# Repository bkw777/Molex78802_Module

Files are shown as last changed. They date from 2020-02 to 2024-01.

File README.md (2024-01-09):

# Molex78802 Module
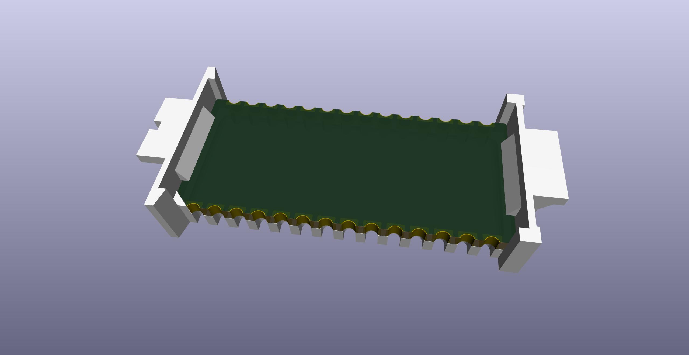
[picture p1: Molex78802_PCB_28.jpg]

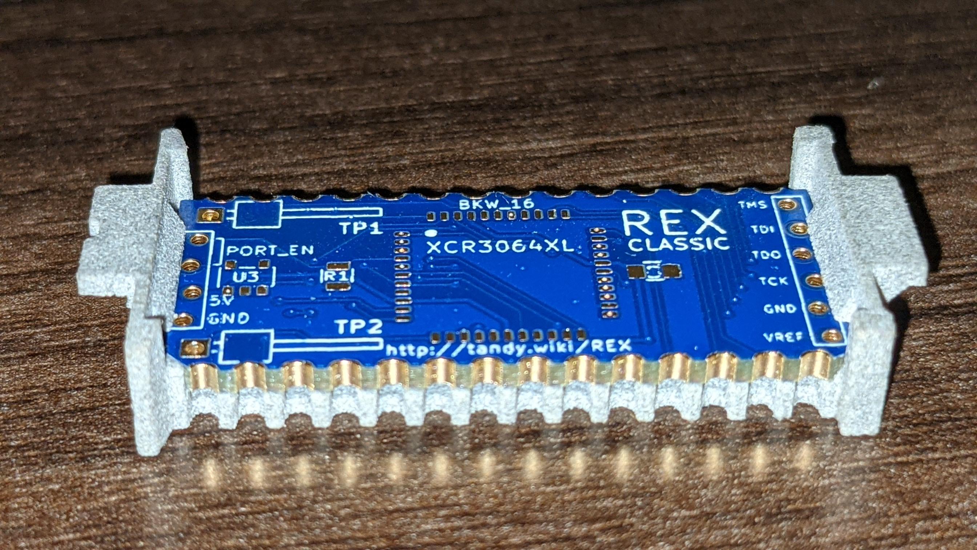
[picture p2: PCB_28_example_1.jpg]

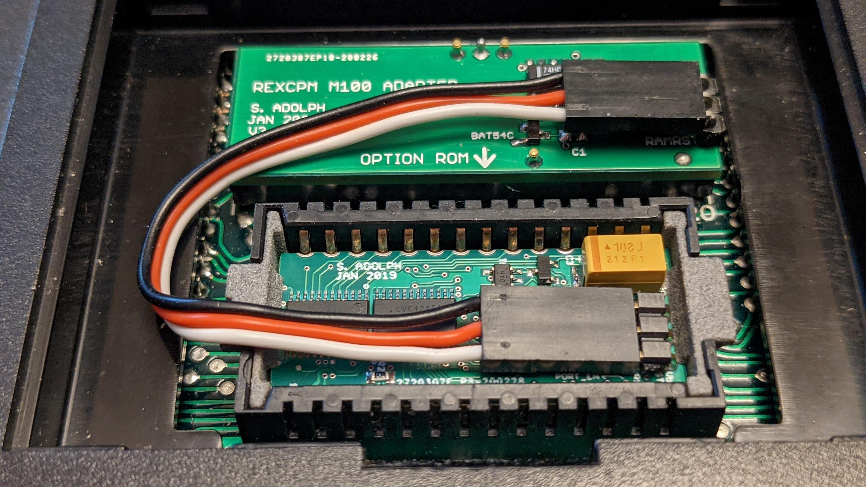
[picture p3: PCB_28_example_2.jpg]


This is a 3d-printable carrier similar to Molex 78802, to fit into a Molex 78805 socket, and a PCB template to use in place of a DIP chip.

The OpenSCAD file generates 2 types of carrier, one type that holds a DIP chip like a normal Molex 78802, and a different form that holds a PCB instead of a DIP.

The KiCAD files are for the matching PCB with the special board outline and castellated edge contacts to fit the PCB carrier. The pcbs are empty starter templates. Copy the entire PCB directory to a new project and rename the kicad_pcb file to a new name to start a new pcb.

Each of those are also available in 24, 28, and 32-pin sizes, as the original Molex [78802](references/050395288_sd_corrected.pdf) & [78805](references/015299282_sd_corrected.pdf) were.  
Though almost everything uses the 28-pin.

Uses:
* TRS-80/TANDY Model 100, 102, 200, 600
* Kyotronic KC-85
* Epson PX-4, PX-8
* Intermec 9440, Telexon 710, and various other similar hand-held teriminals
* RB5X robot (24-pin!)

http://tandy.wiki/Molex78802_Module  
https://github.com/bkw777/M4ROM  
http://tandy.wiki/Teeprom  
http://tandy.wiki/REX  

You can get 3d printed parts from Shapeways: (all versions) https://www.shapeways.com/shops/bkw  
Or use the STL files with any service.  Hint: Order pcbs like REX or M4ROM from Elecrow and order the carriers (Molex_78802_PCB_28.stl) in Nylon from them too all on the same order.
<!-- Sculpteo has a $50 minimum order, if you order less than $50 worth of parts before tax & shipping, then they charge you the difference. So you have to order 8 or 9 carriers minimum. -->
<!-- Or Sculpteo: [PCB24](https://www.sculpteo.com/en/print/molex78802_pcb_24-4/xMikpkmg), [PCB28](https://www.sculpteo.com/en/print/molex78802_pcb_28-13/Bw4x3yG6), [PCB32](https://www.sculpteo.com/en/print/molex78802_pcb_32-3/zmUBXFK4), [DIP24](https://www.sculpteo.com/en/print/molex78802_dip_24/P2V6xXt8), [DIP28](https://www.sculpteo.com/en/print/molex78802_dip_28-7/LX6JbLYc), [DIP32](https://www.sculpteo.com/en/print/molex78802_dip_32/sJC8nkke). -->

Brian K. White - b.kenyon.w@gmail.com

## DIP 24  
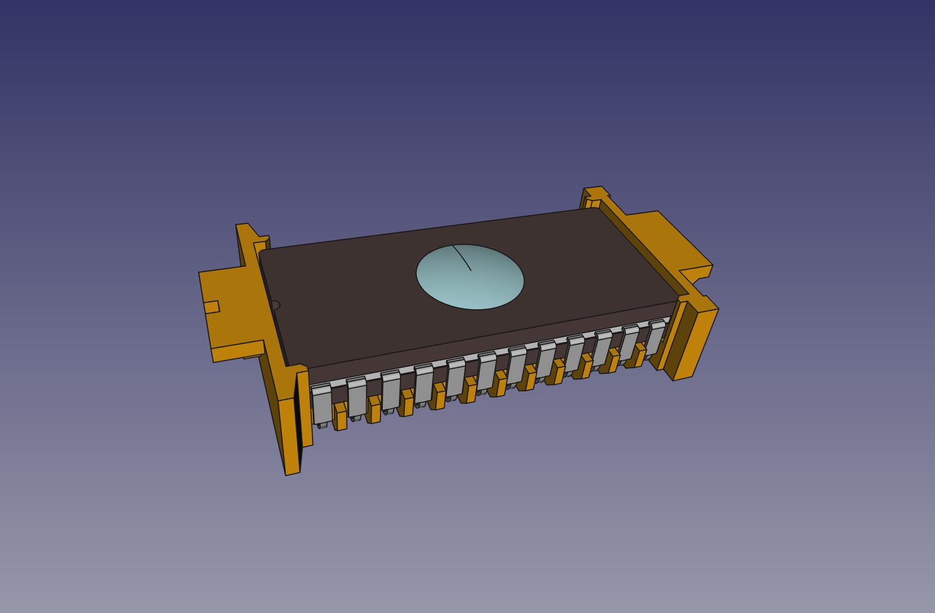
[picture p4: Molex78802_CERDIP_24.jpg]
  
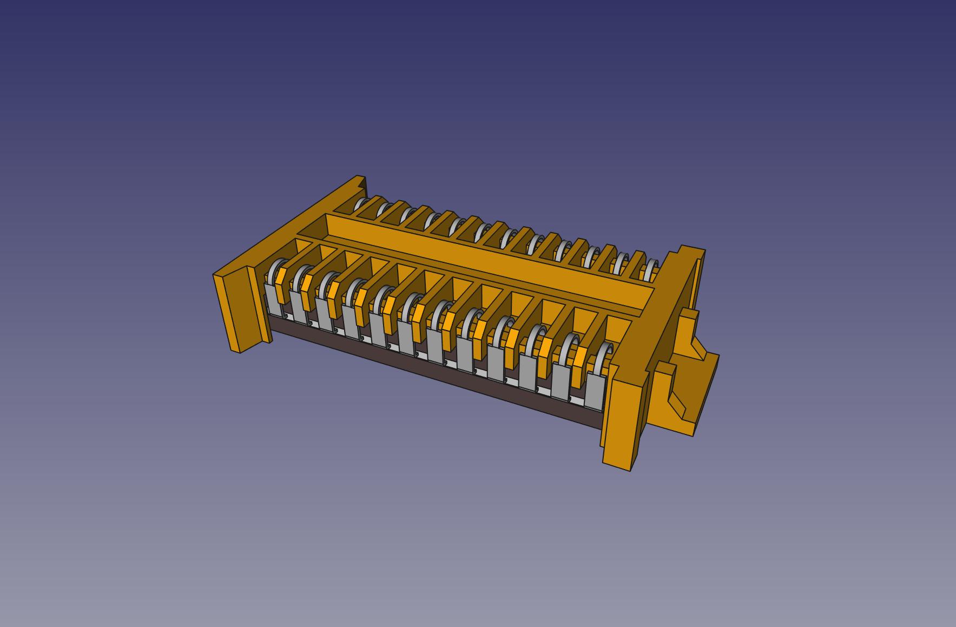
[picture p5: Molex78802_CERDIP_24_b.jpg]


## DIP 28  
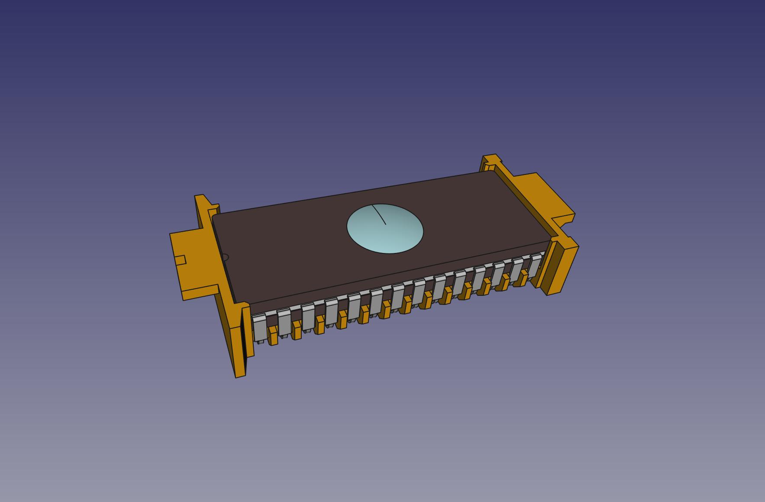
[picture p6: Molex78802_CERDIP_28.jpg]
  
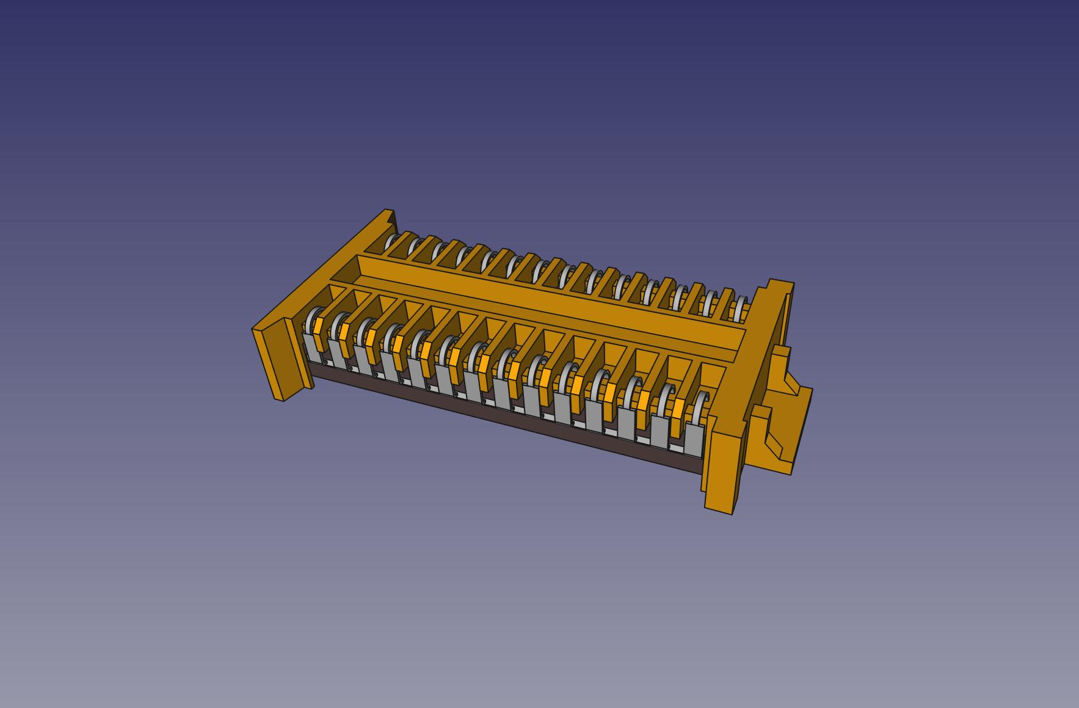
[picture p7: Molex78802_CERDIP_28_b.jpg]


## DIP 32  
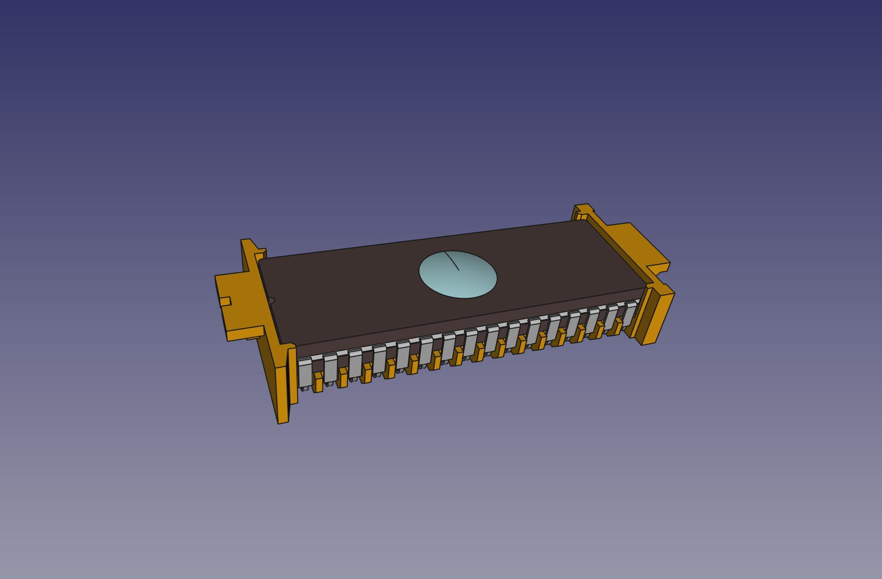
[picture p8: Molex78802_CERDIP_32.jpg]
  
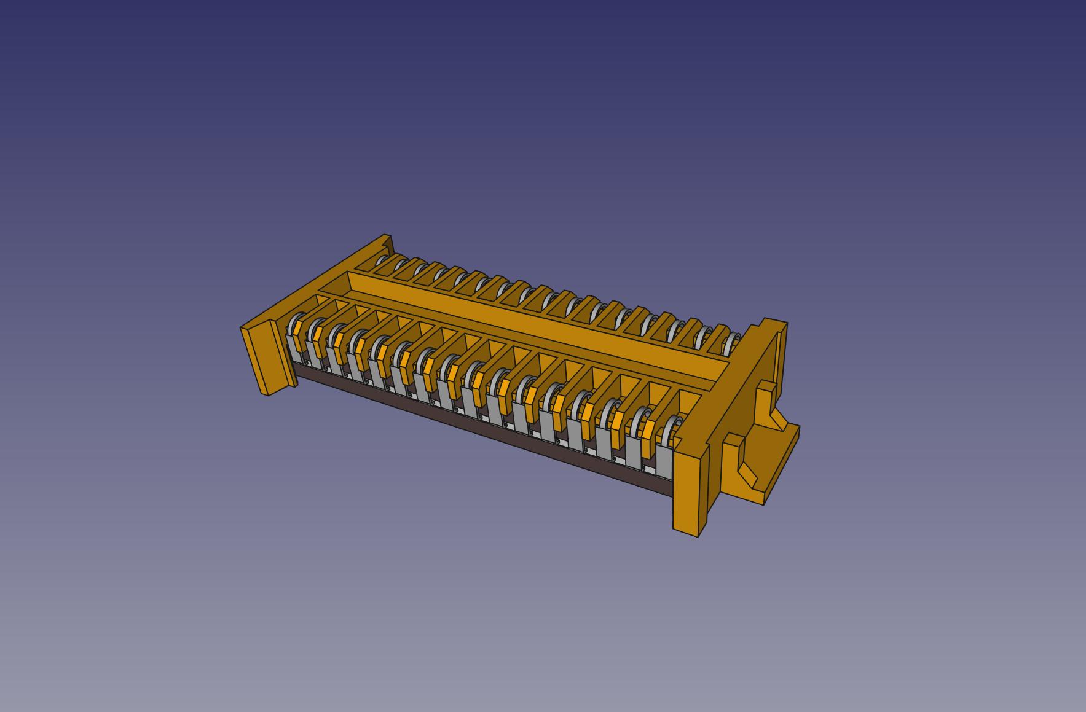
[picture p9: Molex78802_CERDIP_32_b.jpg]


## PCB 24  
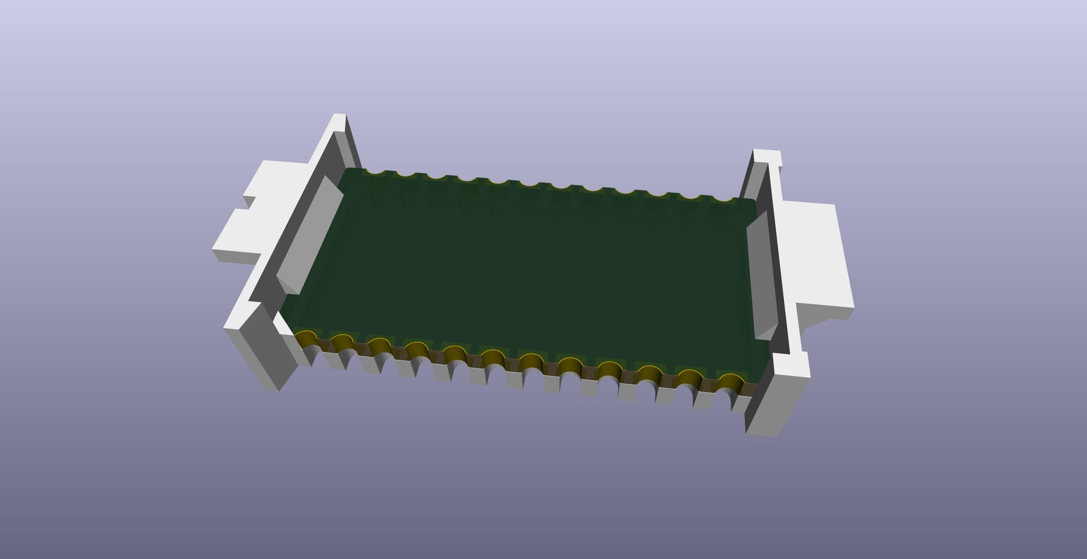
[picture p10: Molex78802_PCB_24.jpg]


## PCB 28  


## PCB 32  


***May 19 2021 - The PCB outline changed slightly after [v003](https://github.com/bkw777/Molex78802_Module/tree/v003). The PCB is a little wider now. Old boards will be a little loose side-to-side in new carriers, and probably the polarity chamfer won't prevent inserting an old board backwards in a new carrier. New boards won't fit into old carriers, although the difference is small enough that you could just sand the corners down a little and they should work fine. If you have either old carriers or old boards that you want to get the exact matching counterparts for, then go to [Release v003](https://github.com/bkw777/Molex78802_Module/releases/tag/v003).***

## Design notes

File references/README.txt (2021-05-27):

* 015299282_sd_corrected.pdf
  The data sheet for the socket has an error for the width of the interior cavity.
  It correctly says 0.665 for the width in inches, but incorrectly says 19.90 for the same dimension in mm.
  0.665 inches = 16.891 mm
  The corrected pdf changes the text "(19.90)" to "(16.89)"

* 050395288_sd_corrected.pdf
  The data sheet for the carrier has a drawing error where DIM.D and DIM.F both line up with the same feature,
  the outside edge of the left end, and no dimension lines up with the recessed edge on the left side.
  The numbers in the chart show that DIM.D is the outside edge, and DIM.F is the recessed edge.
  The corrected pdf moves the left drawing line for DIM.F slightly to the right to line up with the recessed edge on the left side.

* DIP-##_crimped.step
  Created manually using FreeCAD, starting from a DIP-28 .step from KiCAD's library.
  Used to check fitment virtually and to generate renders.

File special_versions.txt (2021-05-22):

Aside from the "DIP" and "PCB" versions, there is also a hidden "maxpcb" version.

To generate a maxpcb version, run:  
    cd Carrier && make variants=maxpcb

The maxpcb version is difficult to use, incompatible with normal REX/Teeprom/Meeprom boards, and probably never needed, so it's hidden for simplicity. But it exists to provide an option if ever really needed, that gives the absolute most possible usable pcb real-estate.

The normal PCB version has:
* A ledge running aoround the perimeter for the pcb to rest on, which consumes a 0.7mm border on all 4 sides on the bottom.
* 2 snap wedges on top that hold the pcb down, which consumes 2 1x10mm chunks on the top.
* A polarity chamfer in one corner which consumes 1.7mm of that corner on top and bottom

The maxpcb replaces all those mechanisms for holding the pcb in place with holes in the end walls, and you design the pcb board outline to have prongs that stick into those holes. This holds the pcb in place in all directions, and polarity is asserted by the fact that one hole is larger. This allows to dispense with the perimiter ledge, the snap wedges, and the chamfer. This allows not only traces but even components to exist right to the edge of the pcb on all 4 sides and on both top & bottom.

There is no kicad template for a maxpcb board at this time.

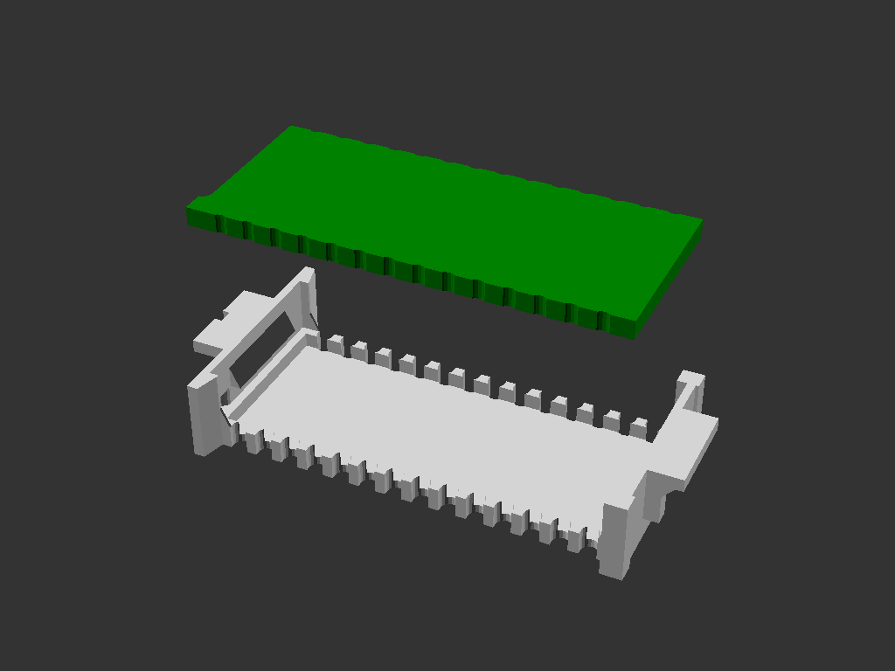
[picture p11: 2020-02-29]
pcb2molex8878_bump.png

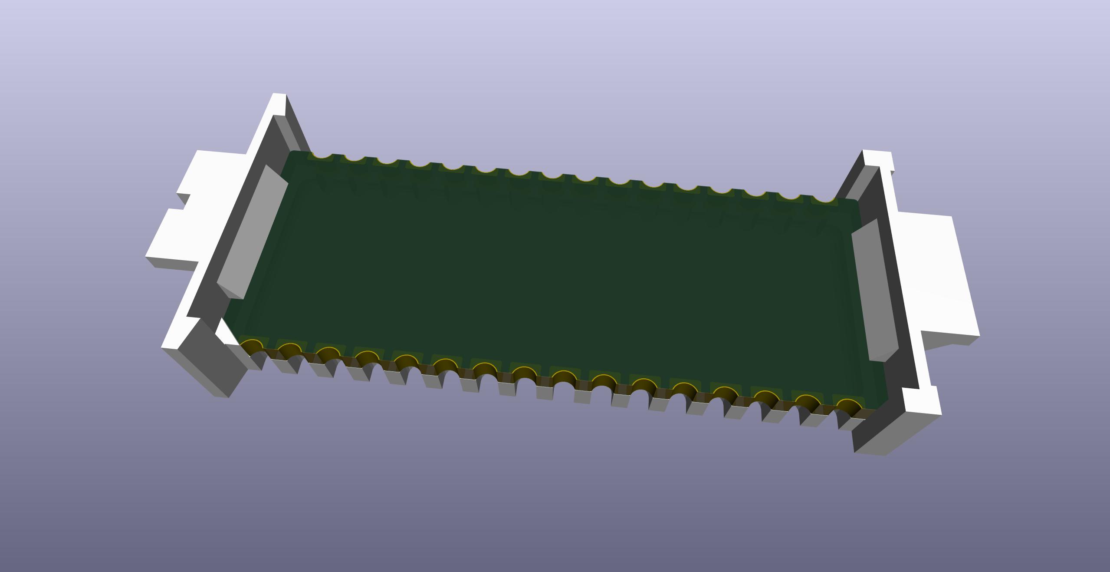
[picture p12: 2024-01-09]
Molex78802_PCB_32.jpg

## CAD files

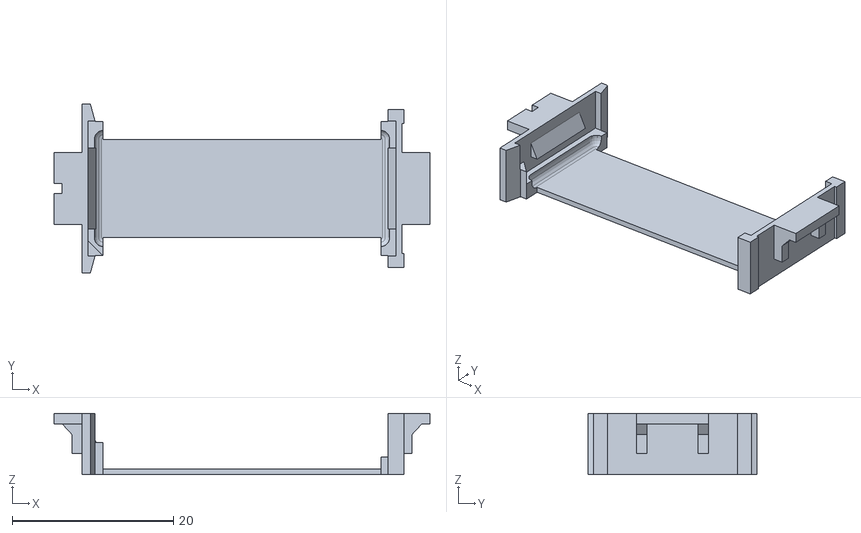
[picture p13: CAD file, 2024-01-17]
Carrier/Molex78802_PCB_28_no_fingers.stl
46.6 x 21.0 x 7.60

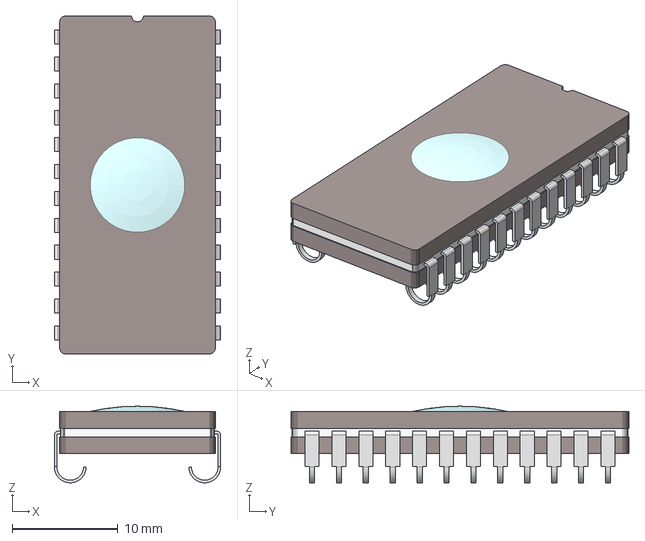
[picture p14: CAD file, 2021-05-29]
references/CERDIP_24_crimped.step
15.7 x 31.9 x 7.24 mm

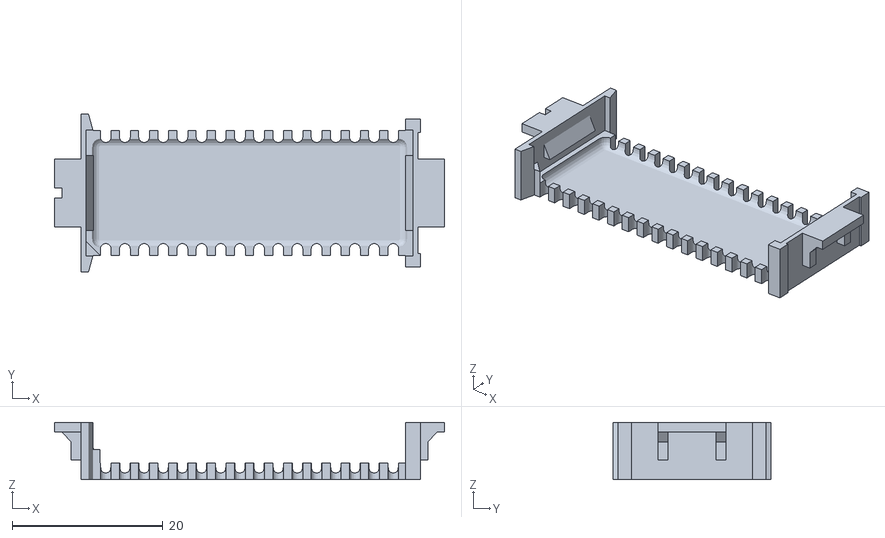
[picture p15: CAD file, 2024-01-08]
Carrier/Molex78802_PCB_32.stl
51.7 x 21.0 x 7.60

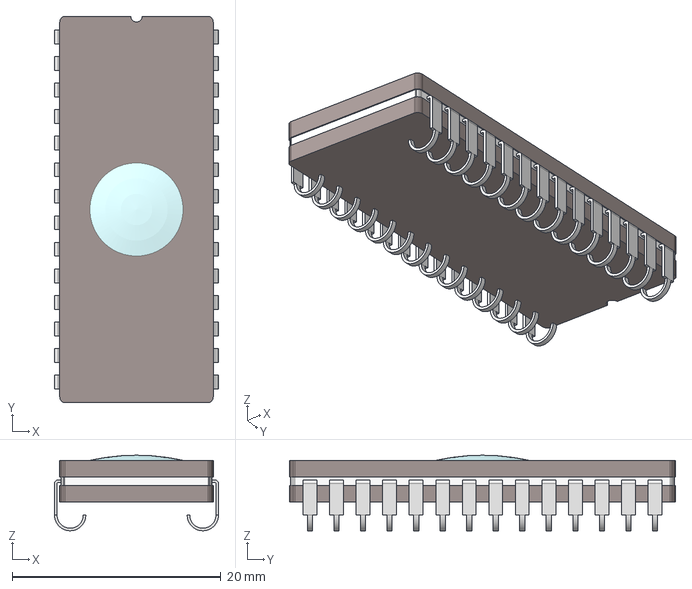
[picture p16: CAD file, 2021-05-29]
references/CERDIP_28_crimped.step
15.7 x 37.0 x 7.24 mm

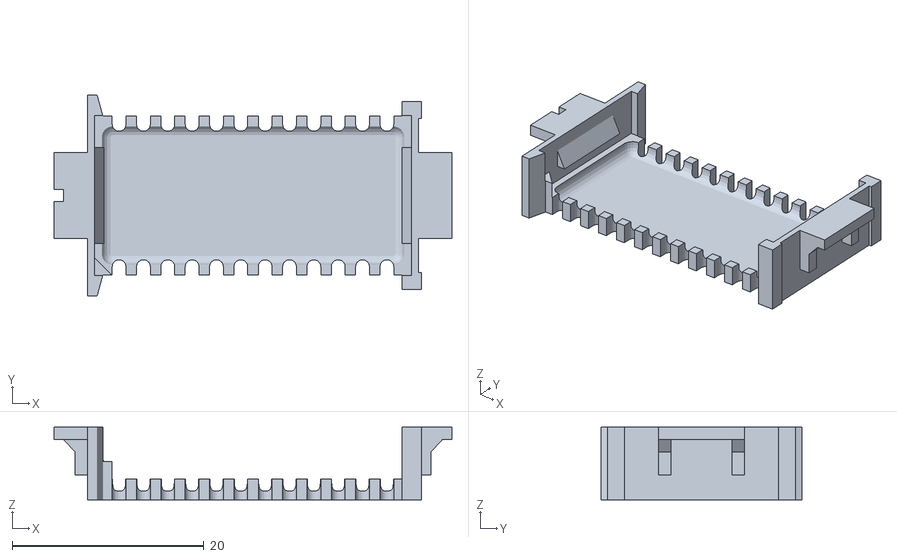
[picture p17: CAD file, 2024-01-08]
Carrier/Molex78802_PCB_24.stl
41.5 x 21.0 x 7.60

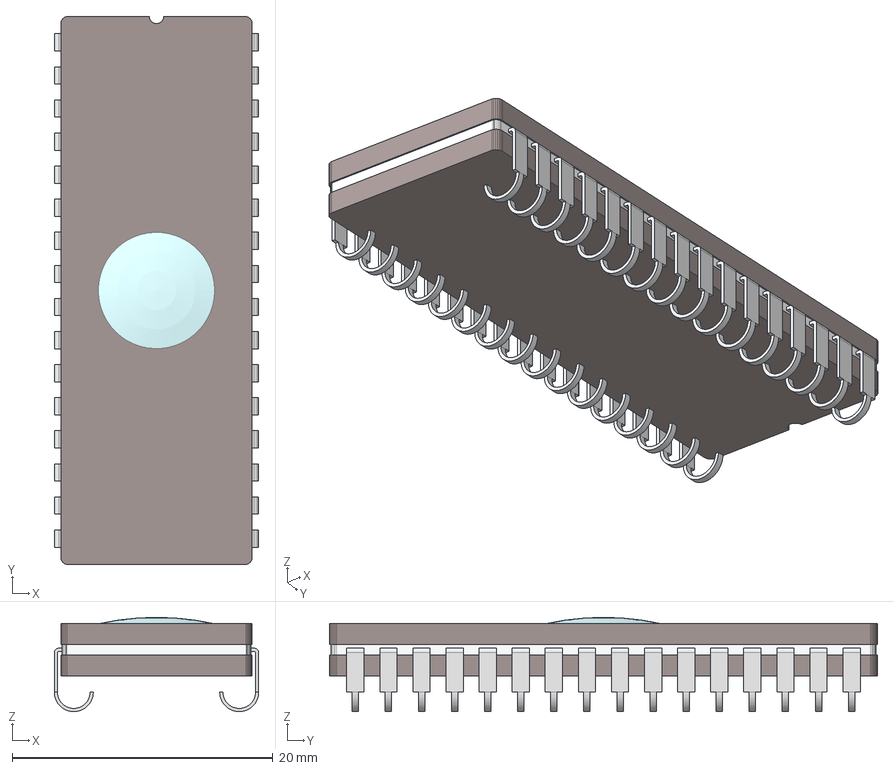
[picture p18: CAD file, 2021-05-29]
references/CERDIP_32_crimped.step
15.7 x 42.1 x 7.24 mm

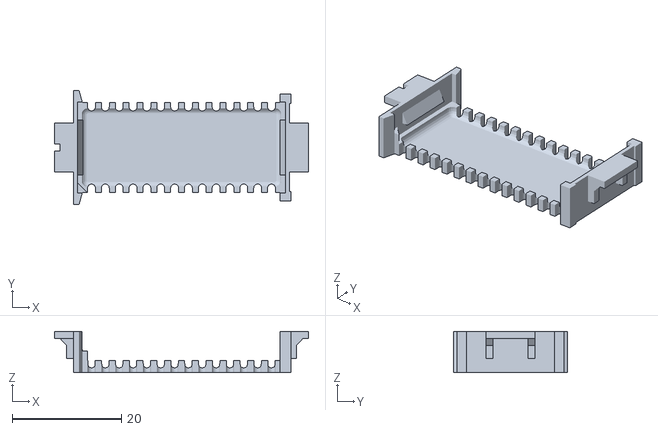
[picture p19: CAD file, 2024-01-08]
Carrier/Molex78802_PCB_28.stl
46.6 x 21.0 x 7.60

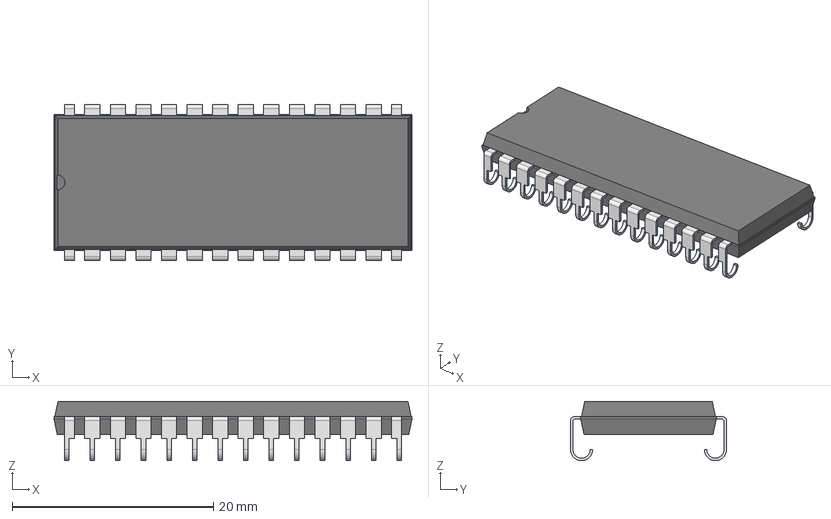
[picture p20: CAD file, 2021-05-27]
references/DIP-28_crimped.step
35.6 x 15.5 x 5.90 mm

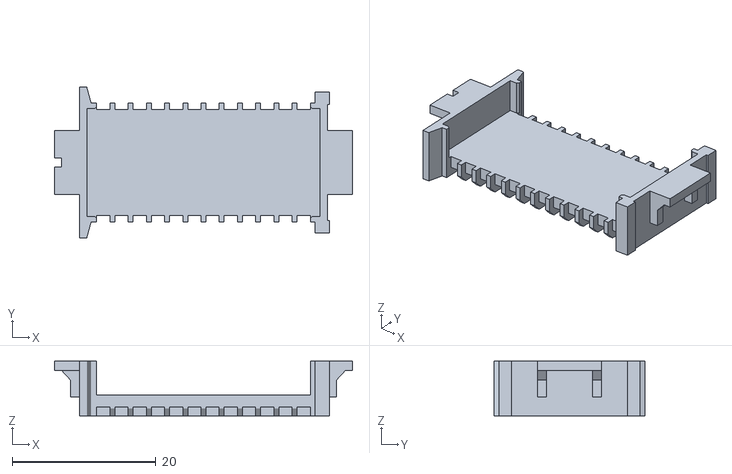
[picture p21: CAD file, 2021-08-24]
Carrier/Molex78802_DIP_24.stl
41.5 x 21.0 x 7.60

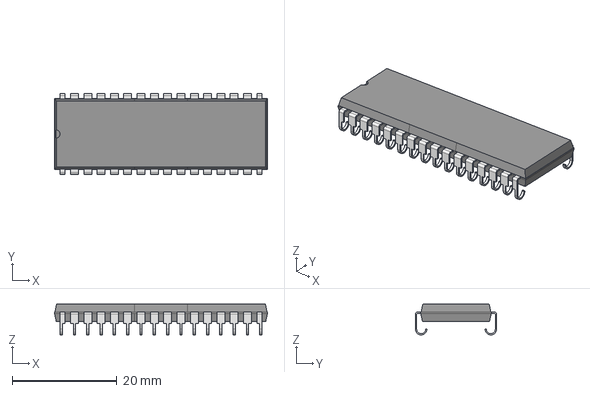
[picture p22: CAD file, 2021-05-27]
references/DIP-32_crimped.step
40.6 x 15.5 x 5.90 mm

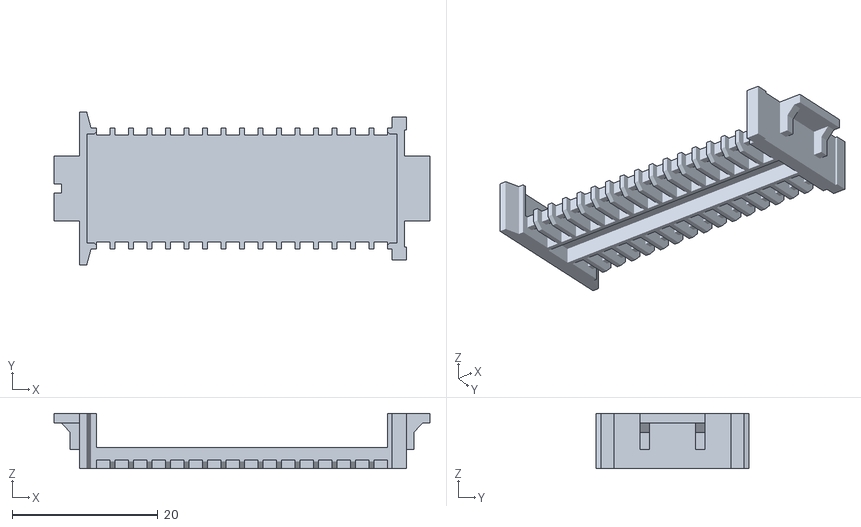
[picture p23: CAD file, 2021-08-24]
Carrier/Molex78802_DIP_32.stl
51.7 x 21.0 x 7.60

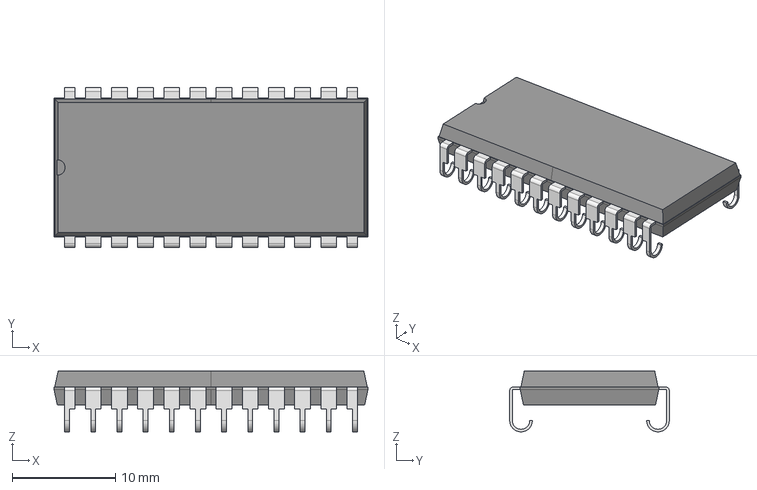
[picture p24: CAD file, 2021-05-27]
references/DIP-24_crimped.step
30.5 x 15.5 x 5.90 mm

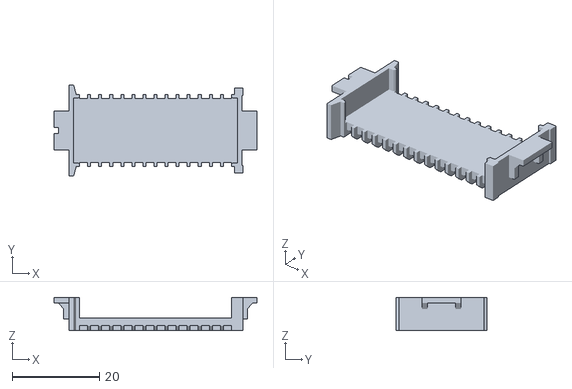
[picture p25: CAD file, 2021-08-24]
Carrier/Molex78802_DIP_28.stl
46.6 x 21.0 x 7.60

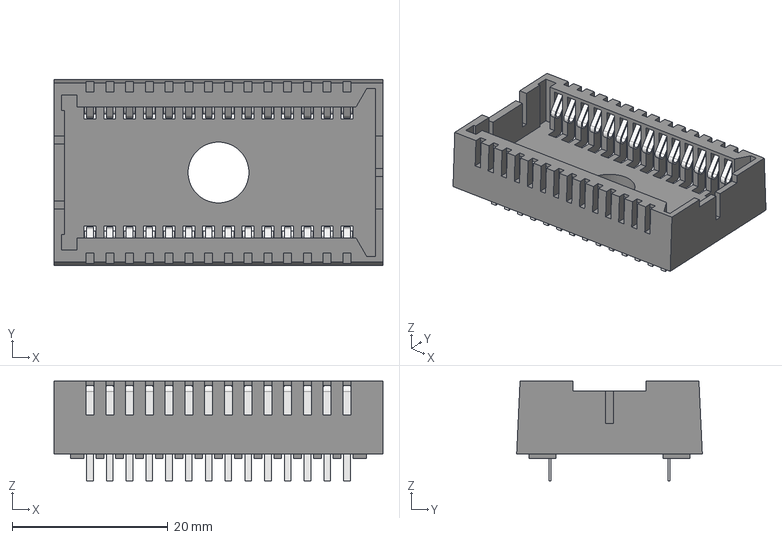
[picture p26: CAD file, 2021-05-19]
references/Molex_78805.step
42.3 x 23.9 x 12.9 mm

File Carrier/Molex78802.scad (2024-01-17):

/*
   OpenSCAD model of a DIP or PCB Molex 78802 carrier to fit a Molex 78805 socket. 
   Works with Molex78802_PCB.kicad_pcb .

   Produces 9 possible versions
   There are 3 variants: "DIP", "PCB", and "maxpcb"
   And each variant may be generated with any even number of pins,
   though Molex 78802/78805 only came in 24, 28, and 32.

   Uses:
   28-pin "DIP" version takes a DIP-28 chip, and replaces an original Molex78802
   28-pin "PCB" version takes PCB like REX#, REXCPM, REX_Classic_BKW, Teeprom, Meeprom

   Brian K. White - b.kenyon.w@gmail.com
   http://tandy.wiki/Molex78802_Module
   https://github.com/aljex/Molex78802_Module/
*/

// -------------------------------------------------------------------------
// UNITS: mm

// "DIP" - fits a standard DIP chip, not a PCB
// "PCB" - 28-pin version of this fits REX#, REXCPM, REX_Classic_BKW, Teeprom, Meeprom, 4ROM_TANDY, 4ROM_27256 - *default*
// "maxpcb" - maximum possible usable pcb real-estate, difficult to use
// Type: "DIP", "PCB", "maxpcb"
variant = "PCB";

// Easier Printing Option - remove the little finger posts
//
// The "PCB" variant has little finger posts supporting the PCB
// between each DIP contact, which are difficult to print even with SLS.
// You can set PCB_fingers to false to remove them.
// The pcb will be unsupported in the middle,
// but the entire pcb is short enough that it should be ok.
// Including the posts is the safest for the user, as it garantees the that pcb
// can not be depressed too far into the socket no matter how hard one presses.
PCB_fingers = true;

// Molex 78802 datasheet shows 24, 28, and 32-pin versions
// Number of pins: 24, 28, 32
pins = 28;

// Temporarily comment out $fn $fs $fa and save for importing into freecad.
// Otherwise freecad only imports the mesh facets, not the source geometry.
// arc smoothness
$fn = 18;

// The DIP and PCB versions work a little differently.
//
// The PCB version references everything from the inside dimensions of the socket
// and works inwards from there. The PCB dimensions are ultimately derived from
// the socket and the limits of the printing technology, to arrive at the largest
// possible pcb that can fit.
//
// For the DIP version, the "pcb" is really a DIP or CERDIP, so for the DIP
// version the the pcb-related measurements are based on ceramic dip standards,
// not the socket.
//
// This makes some of the code look a little schizophrenic and convoluted, sorry.
//
// Some dimensions here are slightly off from the datasheets intentionally,
// as we are also dealing with the limits of SLS printing.

// Fitment Clearance
_fc = 0.05;

// min allowed wall thickness
min_wall = 0.7;

// minimum allowed unsupported wires thickness
min_unsupported_wires = 1.1;

// pin pitch (2.54 is the only valid value)
pitch = 2.54;

// main box-shaped cavity inside socket
// not counting polarity features or contacts
//main_x = 39.6;    // 050395288_sd.pdf 50-39-5288 DIM. F: 39.8 / 015299282_sd.pdf: 40.01
// derived from pins and pitch
main_x = ((pins/2)*pitch)+4.04; // 4.04 is back-derived from the 39.6 value for 28-pin version
main_y = 16.6;    // 050395288_sd.pdf: 16.64 / 015299282_sd.pdf: 16.89
main_z = 7.6;    // Overall height of carrier. Neither datasheet shows, so this is from measuring.

// for the DIP version, the "PCB" dims are actually a ceramic dip body
cerdip_body_y = 14.8;
cerdip_body_x_extra = 2;  // pins/2 * pitch + _extra = body length
cerdip_body_z = 4.5;

// pcb thickness
pcb_thickness = (variant=="DIP") ? cerdip_body_z : 1.7;

// pcb cavity (pcb will be smaller to fit inside this space)
//pcb_x = (variant=="DIP") ? 37.5 : main_x-1.5;     // leave walls >= 0.7  ( (main_x-pcb_x)/2 >= 0.7 )
pcb_x = (variant=="DIP") ? ((pins/2)*pitch)+cerdip_body_x_extra : main_x-min_wall*2;     // leave walls >= 0.7  ( (main_x-pcb_x)/2 >= 0.7 )

// DIP version could actually have no side walls, same as maxpcb.
// The dip legs hold the chip in place.
// The "eby" branded carrier (eby 9775-548-28) has no side walls.
pcb_y = (variant=="DIP") ? cerdip_body_y+_fc*2 : (variant=="maxpcb") ? 3+main_y+3 : main_y;

pcb_z = _fc+pcb_thickness+_fc;

// pcb elevation - bottom of pcb above socket floor
pcb_elev = (variant=="DIP") ? 2.9 : 2.2;  // min 1.9 - max 2.4

// cavity in bottom tray for backside components and through-hole legs
perimeter_ledge = (variant=="maxpcb")?0:min_wall+0.1;
pocket_x = pcb_x-perimeter_ledge*2;
//pocket_y = pcb_y-perimeter_ledge*2;
pocket_y = pcb_y-min_unsupported_wires*2;
if(pcb_x-pocket_x < 1 && pcb_y-pocket_y < 1 && variant != "maxpcb") echo("ERROR: Unsupported PCB! Reduce pocket_x or pocket_y, or increase perimeter_ledge");
pocket_floor = min_wall; // floor thickness
pocket_z = pcb_elev - pocket_floor;
pocket_fillet_radius = 1.1;

// wedge-shaped corner posts at pin1 & pin28
cpwedge_xwide = 1.6;    // thick end of wedge
cpwedge_xnarrow = 1;    // thin end of wedge
cpwedge_y = 21;         // total Y outside end to end both posts

// box-shaped corner posts at pin14 & pin15
cpbox_x = 2;    // X len of 1 post
cpbox_y = 1.75;    // Y width of 1 post
cpbox_xe = 0.3;   // X extends past main_x
cpbox_yo = 19.6;  // total Y outside end to end both posts

// socket polarity blades
blade_z = 5.0;            // height from top of main_z to bottom of blade
blade_xwide = 2.5;        // wide part extend past main_x
blade_xnarrow = 1.3;      // narrow part extend past main_x
blade_thickness = 1.3;

// finger pull wings
wing_y = 8.95;
wing_x = 3.5;             // extend past main_x
wing_thickness = blade_thickness;

// pcb retainer wedges
ret_x = 1;        // overhang
ret_y = 10;       // length
ret_z = 2;        // height

// castellated edge contacts
// get the drill size & position values from the footprint in KiCAD
// PCB/000_LOCAL.pretty/Molex78802_PCB_28.kicad_mod
// drill size and position for castellated edge contacts
c_width = pitch-min_unsupported_wires; // width of space to cut away from the carrier body around each contact
//c_y = 14.1; // shortest distance between opposing contacts in empty socket (uncompressed contacts)
c_y = 13.5; // shortest distance between opposing contacts in empty socket (uncompressed contacts)
c_positions = pins/2;
c_x_full = c_positions * pitch;
c_diff = pitch - c_width;
c_x_min = c_x_full - c_diff;
c_fingers = (variant=="maxpcb") ? false : PCB_fingers;

// Stuff for "DIP" variant
pin_pocket_width = pitch-min_wall;
pin_pocket_len = 3.5; // inside face of pin_bend_wall towards center
pin_bend_wall_thickness = 1;
pin_bend_wall_outsides = 14.7; // outside face to opposite outside face
pin_bend_wall_height = 1.7; // pcb_elev to bottom of wall that pins bend over

/////////////////////////////////////////////////////
// pcb polarity - polarity of the pcb in the carrier
// (not polarity of the carrier in the socket)

// pcb polarity chamfer
// derived from contacts & clearance - rounded to 0.1 precision
pcb_polarity_chamfer = (variant=="PCB") ? round((pcb_x/2-c_x_min/2)*10)/10 : 0; // pin 1 corner polarity chamfer

// pcb prongs for "maxpcb" variant
// corner prongs
prong_w = (variant=="maxpcb") ? 2.5 : 0;
prong_cyl = (main_x-pcb_x)/2;  // aka _pbh - _fc/2
_pbw = prong_w * 2;     // one prong double width for polarity
_pbh = (variant=="maxpcb") ? main_x/2-pcb_x/2+cpbox_xe+_fc/2 : 0;  // bump height = end wall thickness

// overlap/overextend - extend cut shapes this far beyond the outside surfaces they cut from,
// and embed union shapes this far beyond the surfaces into the shapes they join to
// to prevent zero-thickness planes and other noise in renders and mesh exports.
o = 0.2;  // enough to see clearly in preview

legacy_side_wall_chamfer = 0.5; // size of chamfers on inside side walls for the legacy variant - acommodate mill radius in pcb edge cuts

// Display some calculated values in the console, (View -> [ ] Hide Console)
// so that it's easy to copy them to KiCAD,
assert(pins>=2 && pins%2==0);
if(variant!="DIP"){
echo("###################################################################");
echo("#");
echo("### Use the following dimensions in KiCAD");
echo("### Carrier Variant,Pins",variant,pins);
echo("#");
echo("# PCB: Length,Width",pcb_x-_fc*4,main_y); // remove an extra _fc on both ends, needs a little more room to allow for print quality
if(variant=="PCB"){
  echo("# Polarity Chamfer:",pcb_polarity_chamfer);
  echo("# Backside Pocket: Length,Width,Depth", (pocket_x>pcb_x-_fc*2)?pcb_x-_fc*2:pocket_x-_fc*2 , (pocket_y>pcb_y-_fc*2)?round((pcb_y-_fc*2)*10)/10:pocket_y-_fc*2 , (pocket_z>pcb_elev)?pcb_elev:pocket_z );
}
if(variant=="maxpcb"){
  echo("# Polarity Bump: Width,Height",_pbw,_pbh);
  echo("# Prongs: Width,Height",prong_w,_pbh);
  echo("# Backside Pocket: Length,Width,Depth", pcb_x-_fc*2, main_y-_fc*2, (pocket_z>pcb_elev)?pcb_elev:pocket_z );
}
echo("#");
echo("###################################################################");
}
// debugging
//echo("### main_x ###",main_x);

// ===============================================================
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

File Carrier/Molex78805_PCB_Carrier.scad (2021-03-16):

// OpenSCAD model of Molex78805_PCB_Carrier
// for Molex78805_PCB.kicad_pcb

// Carrier to hold a PCB in place of a DIP28 chip
// in the Molex 78805 socket found in some vintage computers.
// Examples: Tandy Model 100, 102, 200, 600
//     Epson PX-4, PX-8

// Brian K. White - b.kenyon.w@gmail.com
// http://tandy.wiki/Molex78805_PCB_Module
// https://github.com/aljex/Molex78805_PCB_Module/

// -------------------------------------------------------------------------
// UNITS: mm
// VARIANTS: chamfer pin unpolarized legacy

// Which version of the carrier to produce:
// "legacy" - fits REX_bkw_c8 and original Teeprom
// "pin" - fits REX_bkw_c9
// "chamfer" - fits REX_bkw_c11 and current Teeprom - *current default*
// "bump" - carrier wall has a hole for a male polarity bump on a pcb edge
// "max" - maximum usable pcb real-estate
variant = "chamfer"; // Just the default. Makefile overrides this via "-D ..."

// Original REX1 can use the "bump" version, if you are willing to sand the pcb edges down a little.

// PCB dimensions are derived from a mix of constraints.

// PCB main outside X,Y dimensions are ultimately derived from the inside of the Molex 78805 socket.
// Socket interior, minus fitment clearance, minus carrier body, minus fitment clearace = PCB X,Y
// Then the chamfer on the PCB is derived from the PCB X dim and the edge of the pin1 contact.
// Then the chamfer in the carrier is derived from the chamfer on the PCB, minus clearance.


_fc = 0.1;  // fitment clearance

// main box-shaped cavity inside socket
// not counting polarity features or contacts
main_x = 39.6;    // 050395288_sd.pdf 50-39-5288 DIM. F: 39.8 / 015299282_sd.pdf: 40.01
main_y = 16.6;    // 050395288_sd.pdf: 16.64 / 015299282_sd.pdf: 16.89
main_z = 7.48;    // neither datasheet shows the carrier height nor the socket depth

// pcb thickness - nominal 1.6
_pz = 1.7; // realistic pcb thickness nominal + 0.1
// pcb thickness - nominal 0.8
//_pz = 0.9; // realistic pcb thickness nominal + 0.1

_mr = 0.836; // pcb edge cut mill radius (0.034")

// pcb cavity (pcb will be smaller)
pcb_x = (variant=="legacy") ? 37.5 : main_x-1.5;     // leave walls >= 0.7  ( (main_x-pcb_x)/2 >= 0.7 )
pcb_y = (variant=="legacy") ? 15.3 : (variant=="max") ? main_y+0.002 : 16.1;
pcb_z = _pz+_fc;

// 1.6mm pcb
pcb_elev = 2.2;   // bottom of pcb above socket floor. Min 1.9 - Max 2.4
// 0.8mm pcb
//pcb_elev = 2.6;   // bottom of pcb above socket floor.

// Derived/calculated dimensions for the actual PCB
_px = pcb_x - _fc;
_py = pcb_y - _fc;
_pe = pcb_elev + _fc/2;

// cavity in bottom tray for backside components and through-hole legs
perimeter_ledge = (variant=="max")?0:0.8;
pocket_x = pcb_x-perimeter_ledge*2;
pocket_y = pcb_y-perimeter_ledge*2;
if(pcb_x-pocket_x < 1 && pcb_y-pocket_y < 1 && variant != "max") echo("ERROR: Unsupported PCB! Reduce pocket_x or pocket_y, or increase perimeter_ledge");
pocket_floor = 0.8; // floor thickness. fab limit 0.7 min
pocket_z = pcb_elev - pocket_floor;

// wedge-shaped corner posts at pin1 & pin28
cpwedge_xwide = 1.6;    // thick end of wedge
cpwedge_xnarrow = 1;    // thin end of wedge
cpwedge_y = 21;         // total Y outside end to end both posts

// box-shaped corner posts at pin14 & pin15
cpbox_x = 2;    // X len of 1 post
cpbox_y = 1.75;    // Y width of 1 post
cpbox_xe = 0.3;   // X extends past main_x
cpbox_yo = 19.6;  // total Y outside end to end both posts

// socket polarity blades
blade_z = 5.2;            // height from top of main_z to bottom of blade
blade_xwide = 2.5;        // wide part extend past main_x
blade_xnarrow = 1.4;      // narrow part extend past main_x
blade_thickness = 1.4;

// finger pull wings
wing_y = 8.95;
wing_x = 3.2;             // extend past main_x
wing_thickness = 1.2;

// pcb retainer wedges
ret_x = 1;        // overhang
ret_y = 10;       // length
ret_z = 2;        // height
// narrow wedge
//ret_y = 2;       // length
//ret_z = main_z - pcb_elev - pcb_z; // height
// with daughterboard
//ret_z = main_z - pcb_elev - pcb_z - pcb_z; // height

// castellated edge contacts
// get the drill size & position values from the footprint in KiCAD
// PCB/000_LOCAL.pretty/Molex78805_PCB.kicad_mod
// drill size and position for castellated edge contacts
c_drill_diameter = 1.6;
c_drill_y = 8.6; // pcb center to drill center
c_spacing = 2.54; // edge contact spacing
c_number = 28; // number of edge contacts
c_width = 1.6; // width of space to cut away from the carrier body around each contact
c_y = 14.1; // distance between opposing contacts in empty socket
c_positions = c_number/2;
c_x_full = c_positions * c_spacing;
c_diff = c_spacing - c_width;
c_x_min = c_x_full - c_diff;

/////////////////////////////////////////////////////
// pcb polarity - polarity of the pcb in the carrier
// (not polarity of the carrier in the socket)

// pcb polarity chamfer
// derived from contacts & clearance - rounded to 0.1 precision
pcb_polarity_chamfer = (variant=="chamfer") ? round((pcb_x/2-c_x_min/2-_fc/2)*10)/10 : 0; // pin 1 corner polarity chamfer
// hard-coded
//pcb_polarity_chamfer = (variant=="chamfer") ? 1.8 : 0; // pin 1 corner polarity chamfer

// pcb polarity pin
pin_x = 14.53;                    // location center X
pin_y = 3.4;                      // location center Y
pin_z = pcb_elev+pcb_z-0.2;       // top of pin, 0.2 below top of pcb
pin_d = (variant=="legacy") ? 2.6 : 2;       // diameter of PIN. hole in pcb is 2*_fc larger
pcb_polarity_hole_d = pin_d + 2*_fc;         // diameter of HOLE

// pcb polarity bump
pcb_polarity_bump_width = (variant=="max") ? 4 : 2;     // bump width - actual size of pcb shape, not including _fc padding
_pbw = (variant=="bump"||variant=="max") ? pcb_polarity_bump_width : 0;
_pbh = (variant=="bump"||variant=="max") ? main_x/2-pcb_x/2+_fc/2 : 0;  // bump height = end wall thickness

// corner prongs
prong_w = (variant=="max") ? 2 : 0;
prong_cyl = (main_x-pcb_x)/2;  // aka _pbh - _fc/2

o = 0.1;  // overcut - extend cut shapes beyond the outside surfaces they cut from, to prevent zero-thickness planes in previews, renders, & mesh outputs
legacy_side_wall_chamfer = 0.5; // size of chamfers on inside side walls for the legacy variant - acommodate mill radius in pcb edge cuts

$fn=18; // arc smoothness

hide_pcb = false;  // overridden by Makefile, hide %pcb() so that scad-to-step.py only sees the carrier object

// Display some calculated values in the console,
// so that it's easy to copy them to KiCAD,
echo("###################################################################");
echo("#");
echo("### Use the following dimensions in KiCAD");
echo("### Carrier Variant",variant);
echo("#");
echo("# PCB: Length,Width",_px,round(_py*10)/10);
if(variant=="chamfer")
  echo("# Polarity Chamfer:",pcb_polarity_chamfer);
if(variant=="bump"||variant=="max")
  echo("# Polarity Bump: Width,Height",_pbw,_pbh);
if(variant=="pin" || variant=="legacy")
  echo("# Polarity Hole: X,Y,Diameter",pin_x,pin_y,pcb_polarity_hole_d);
if(variant=="max"){
  echo("# Prongs: Width,Height",prong_w,_pbh);
  echo("# Backside Pocket: Length,Width,Depth", _px, round(_py*10)/10, (pocket_z>pcb_elev)?pcb_elev:pocket_z );
}else{
  echo("# Backside Pocket: Length,Width,Depth", (pocket_x>_px)?_px-_fc:pocket_x-_fc , (pocket_y>_py)?round((_py-_fc)*10)/10:pocket_y-_fc , (pocket_z>pcb_elev)?pcb_elev:pocket_z );
}
//echo("#");
//echo("# Daughterboard backside components:", main_z - _pe - _pz - _pz);
echo("#");
echo("###################################################################");

// ===============================================================

module mirror_copy(vector){
  children();
  mirror(vector) children();
}

// socket polarity blade
module blade(){
  rotate([90,0,0])
    translate([0,-blade_z+main_z/2,0])
      linear_extrude(blade_thickness)
        polygon([
          [0,0],
          [0,blade_z],
          [blade_xwide,blade_z],
          [blade_xwide,blade_z-wing_thickness],
          [blade_xnarrow,blade_z-wing_thickness*2],
          [blade_xnarrow,0]
        ]);
}

module daughterboard () {
  translate([0,0,_pz/2+main_z/2-_pz]) cube([_px,_py,_pz],center=true);
}
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

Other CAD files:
Carrier/pcb2molex8878_pin.stl
references/50-39-5288.stp
Carrier/pcb2molex8878_max.stl
references/15-41-3281.stp
Carrier/pcb2molex8878.scad
Carrier/pcb2molex8878_bump.stl
references/50-39-5288.stl

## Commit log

2019-07-31 satisfy shapeways 0.7mm min wall rule
    [dip28_pcb_carrier_v4.FCStd, dip28_pcb_carrier_v4.stl, pcb2molex8878.kicad_pcb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]
2019-08-05 line & text size defaults
    [pcb2molex8878.kicad_pcb]
2019-08-12 make polarity hole even# of mils, add gerbers
    [pcb2molex8878-B_Mask.gbr, pcb2molex8878-B_Paste.gbr, pcb2molex8878-B_SilkS.gbr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]
2019-08-16 initial commit - new model from scratch in OpenSCAD
    [pcb2molex8878.scad, pcb2molex8878_scad.stl]
2019-08-16 comments & label
    [pcb2molex8878.scad, pcb2molex8878_scad.stl]
2019-08-16 allow more room for pcb thickness than exactly nominal 1.6mm
    [pcb2molex8878.scad]
2019-08-19 Simple rectangle pcb Larger pcb Further optimized edge contacts footprint Smaller polarity pin & hole Parametric OpenSCAD model for carrier redraw from scratch
    [dip28_pcb_carrier_v4.FCStd, dip28_pcb_carrier_v4.stl, pcb2molex8878.kicad_pcb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]
2019-08-19 chamfer base of polarity pin
    [pcb2molex8878.scad]
2019-08-19 chamfer corner instead of pin & hole
    [pcb2molex8878.kicad_pcb, pcb2molex8878.scad, pcb2molex8878.step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]
2019-08-21 configurable output variants frm same source. tweak several dimensions based on print samples.
    [pcb2molex8878.scad, pcb2molex8878.step]
2019-08-21 update pcb to match carrier
    [pcb2molex8878.kicad_pcb, pcb2molex8878.scad, pcb2molex8878.stl]
2019-08-21 new common scad file for all varants
    [dip28_pcb_carrier_v4.FCStd, dip28_pcb_carrier_v4.stl, pcb2molex8878.kicad_pcb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]
2019-08-22 desperate measures to get a little more bite on the corners. create makefile to generate stls
    [pcb2molex8878.kicad_pcb, pcb2molex8878.scad, pcb2molex8878.stl]
2019-09-03 add Makefile for carrier and increase pcb elevation 0.2mm
    [pcb2molex8878.scad]
2019-09-03 treat .stl as output rather than source
    [pcb2molex8878.stl]
2019-09-03 update pcb with latest carrier
    [pcb2molex8878.kicad_pcb]
2019-09-03 put .stl files back into repo
    [pcb2molex8878.stl, pcb2molex8878_chamfer.stl, pcb2molex8878_legacy.stl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]
2019-09-04 Add freecad macro to generate .step for kicad from Makefile
    [pcb2molex8878.kicad_pcb, pcb2molex8878.scad, pcb2molex8878_chamfer.stl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]
2019-09-17 comments in .scad file
    [pcb2molex8878.scad]
2019-10-17 Maximize backside components space for Steve Adolph
    [pcb2molex8878.kicad_pcb, pcb2molex8878.scad, pcb2molex8878_chamfer.stl]
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2019-10-21 fix fitment clearance around prong detents. improve pcb model
    [pcb2molex8878.kicad_pcb, pcb2molex8878.scad, pcb2molex8878_max.stl]
2019-10-28 supply all files for all variants
    [pcb2molex8878.scad, pcb2molex8878.stl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]
2019-10-28 generate missing stls
    [pcb2molex8878_bump.stl, pcb2molex8878_chamfer.stl, pcb2molex8878_max.stl]
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2019-11-06 add more prongs and more detents to grab carrier better
    [pcb2molex8878.scad, pcb2molex8878_bump.stl, pcb2molex8878_chamfer.stl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]
2019-11-07 fix pocket dims to account for fitment clearance
    [pcb2molex8878.scad, pcb2molex8878_bump.kicad_pcb, pcb2molex8878_bump.stl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]
2019-11-07 fix renders for readme to include pcb
    [pcb2molex8878_bump.stl, pcb2molex8878_chamfer.stl, pcb2molex8878_max.stl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]
2019-11-08 correct backside pocket dims callout on Dwg.User layer
    [pcb2molex8878_bump-B_Mask.gbr, pcb2molex8878_bump-B_SilkS.gbr, pcb2molex8878_bump-Bottom.gbr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]
2019-11-08 show retainer wedges on pcb drawings. add daughterboard in carrier model.
    [pcb2molex8878.scad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]
2020-02-05 slight change to bump
    [pcb2molex8878_bump.stl, pcb2molex8878_chamfer.stl, pcb2molex8878_max.stl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]
2020-02-05 reduce outside X Y dims by 0.1mm for 3d printing variability
    [pcb2molex8878.scad, pcb2molex8878_chamfer.kicad_pcb]
2020-02-05 reduce outside X & Y by 0.1mm for 3d printing variability
    [pcb2molex8878_bump.stl, pcb2molex8878_chamfer.stl, pcb2molex8878_max.stl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]
2020-02-06 remove center prong from both ends of the 'max' variant
    [pcb2molex8878.scad, pcb2molex8878_bump.stl, pcb2molex8878_chamfer.stl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]
2020-02-06 reduce outside X & Y dims by 0.1mm all around
    [pcb2molex8878.scad, pcb2molex8878_bump.kicad_pcb, pcb2molex8878_bump.stl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]
2020-02-06 update 'pin' variant with new dims
    [pcb2molex8878_pin.kicad_pcb]
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2020-02-29 regenerate models and update pcb elevation in kicad footprints
    [pcb2molex8878_bump.kicad_pcb, pcb2molex8878_bump.stl, pcb2molex8878_chamfer.kicad_pcb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]
2020-11-26 soldermask right to edge of edge contacts
    [pcb2molex8878_bump-B_Mask.gbr, pcb2molex8878_bump-B_SilkS.gbr, pcb2molex8878_bump-Bottom.gbr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]
2021-03-16 Rename. Pack away alt variants. Up castellation depth to 0.5mm.
    [Molex78805_PCB-B_Mask.gbs, Molex78805_PCB-B_SilkS.gbo, Molex78805_PCB-Bottom.gbl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]
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2021-05-20 Rename to Molex78802. Add DIP variant. Add 24 and 32 pin versions.
    [Molex78802.scad, Molex78802_DIP_24.stl, Molex78802_DIP_28.stl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]
2021-05-20 pcb corners, dip pin pockets
    [Molex78802.scad, Molex78802_DIP_24.stl, Molex78802_DIP_28.stl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]
2021-05-21 improved fitment all around, simplified the pcb corners, removed junk from the scad model
    [Molex78802.scad, Molex78802_DIP_24.stl, Molex78802_DIP_28.stl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]
2021-05-21 fix notch in finger pull, fix blade and wing thiknesses and lengths
    [Molex78802.scad, Molex78802_DIP_24.stl, Molex78802_DIP_28.stl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]
2021-05-21 thicker thin walls on pcb version
    [Molex78802.scad, Molex78802_DIP_24.stl, Molex78802_DIP_28.stl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]
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2021-05-22 fix the polarity chamfer
    [Molex78802.scad, Molex78802_DIP_24.stl, Molex78802_DIP_28.stl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]
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2021-08-24 increase unsupported wire width to 1.0mm in pcb carrier
    [Molex78802.scad, Molex78802_DIP_24.stl, Molex78802_DIP_28.stl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]
2022-09-11 kicad v6, better castellated pads, add slotted version
    [Molex78802_PCB_24.kicad_pcb, Molex78802_PCB_28.kicad_pcb, Molex78802_PCB_32.kicad_pcb]
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2024-01-08 fillet and widen the fingers
    [Molex78802.scad, Molex78802_PCB_24.stl, Molex78802_PCB_28.stl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]
2024-01-17 option to remove the finger posts for easier printing
    [Molex78802.scad, Molex78802_PCB_28_no_fingers.stl]
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
